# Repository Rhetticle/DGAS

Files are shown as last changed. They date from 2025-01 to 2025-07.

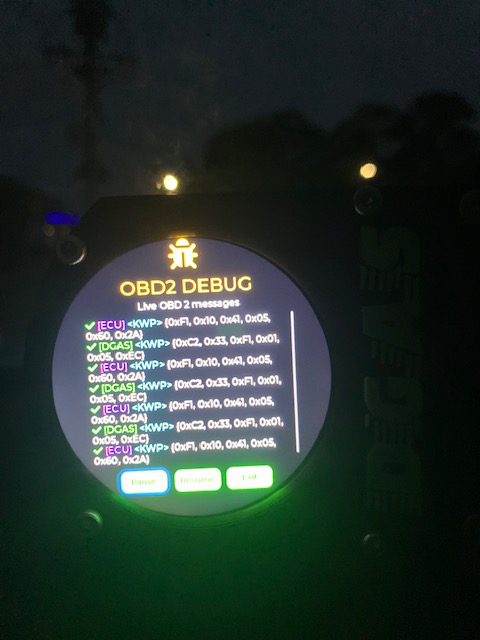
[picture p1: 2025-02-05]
Photos/obd2 debug.jpeg

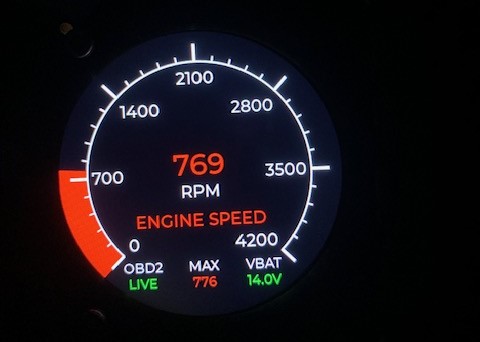
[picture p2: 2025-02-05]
Photos/engine spped small.jpeg

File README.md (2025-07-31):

# DGAS
Digital Gauge Awareness System to be used with any car with an OBD-2 port. 

dgas front


dgas

## Update
Version two of this device is currently in progress including a revised PCB and a major firmware upgrade ([DGOS](https://github.com/Rhetticle/DGOS)) 

## Overview
DGAS is a multi-function digital gauge that can measure any data available on a car's OBD-2 diagnostic port such as engine speed, vehicle speed, coolant temperature, manifold pressure etc. DGAS supports 3 out of the 4 OBD-2 buses namely ISO-9141, ISO-14320 (also known as KWP2000) and ISO-15765 (CAN, most common for newer cars) (SAE J-1850 is not supported). All data measured from the car's ECU is displayed on a 2.1 inch circular TFT-LCD display with a 16-bit color depth.  

DGAS is also capable of performing vehicle and engine diagnostics by reading and displaying current and pending diagnostic trouble codes (DTCs).

## UI

The DGAS UI allows the user to configure and interact with multiple features of the gauge such as measurement parameter as well as watch live OBD2 messages sent from DGAS to the ECU and the response from the ECU which is useful for debugging purposes.

### Main Gauge UI
The gauge UI display the current parameter being measured as well as OBD2 status, maximum parameter value reached so far and battery voltage. Each parameter is color coded.

  

  
  

  

### Menu



### Measure
The measure UI let's the user chose between 1 of 8 different parameters assuming the vehicle DGAS is connected to supports these parameters.



### OBD2 Debug
The OBD2 Debug shows the live data being sent from DGAS and received from the ECU. Each message consists of a header with a status (green tick for ok or red cross for error), a device (either DGAS or ECU) and the bus being used as well as the raw data itself, or an error message if an error occurred on the bus.





### DTC
This UI allows the driver to perform diagnostics on their engine by reading the current/pending diagnostic trouble codes (DTCs). DGAS will send the OBD2 DTC request message and list the codes found if any. For example, if we unplug the cable which connects above the air filter containing the MAF sensor and intake air temperature sensor DGAS reports the following:




As above two codes were found namely P0102 and P0133. We can use SAE-J2012 to find the meaning of each which correspond to MAF and intake air temperature errors as expected.
dtcMeaning

### Self-Test
This screen allows the user to get DGAS to run a test on its hardware. DGAS will test for read access to the entire DRAM memory array and entire flash array as well as test that the accelerometer is also functioning correctly. DGAS will report some statistics on each test such as the time taken to run each test, access speed and acceleration values for the accelerometer.




### Settings
The settings allow the user to configure the default parameter to measure on start-up as well as which OBD2 bus to us on start-up. The configuration is saved to external flash and read on each start-up.




### About
This screen explains what DGAS is and has a QR code which directs users to this GitHub repository



## Hardware Details
* Microcontroller - STM32F746ZGT7 (QFP-144)
* External DRAM - IS42S16100H-7TL (16-Mbit) (50-TSOP)
* External Flash - W25Q256JVEIQ (256-Mbit) (8-WSON)
* TFT-LCD Display - Generic 2.1 inch available [here](https://www.aliexpress.com/item/1005007721123612.html?spm=a2g0o.order_list.order_list_main.11.238a18026Mdnp0) (ST7701 driver IC)
* CAN Transceiver - SN65HVD232QDRQ1 (8-SOIC)
* ISO-9141 Transceiver - L9613B013TR (8-SOIC)
* Accelerometer - LIS3DHTR (16-LGA)

The STM32F746ZGT7 was chosen for it's large 1MB of internal flash (needed to store LVGL code) as well as it's LTDC and FMC peripherals needed to drive the TFT-LCD display and interface with external DRAM respectively. External DRAM was needed to store the frame buffers for the display. As the display was 480x480 with a 16-bit color depth, one frame buffer occupies 460800 bytes. Since DGAS uses double buffering and the TFT-LCD display being used has no internal memory, both buffers must be stored in the DRAM which takes up around half of the 2 MiB available. External flash is being used to store large GUI objects such as images and fonts.

DGAS connects to the car's OBD-2 port via the main DB-15 connector using a DB-15 to OBD-2 cable. The main power connection should be connected to any wire within the car which carries the ignition signal so that DGAS is only powered when the vehicle is on.

The casing for DGAS was designed in Fusion 360 and printed in black ABS as it was found that PLA cannot hold up to the temperatures reached within a car during summer and begins to soften when given enough exposure.

## Firmware Details
Checkout DGAS Firmware for more details on firmware and low-level drivers.
### LVGL
All UI elements for the display were done through the LVGL graphics library as well as the EEZ-Studio UI designer tool.

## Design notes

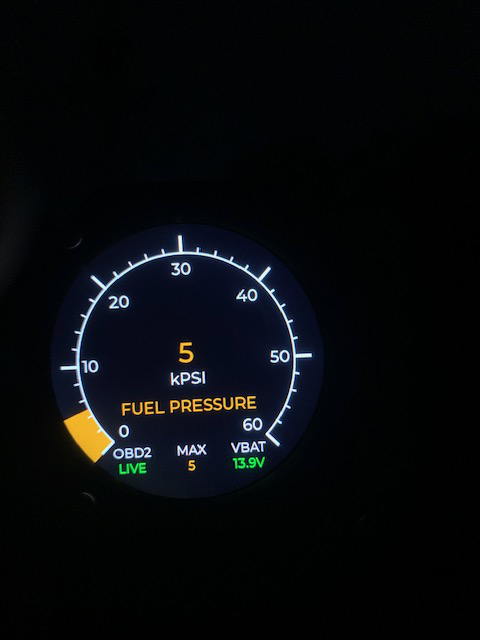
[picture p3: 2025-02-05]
Photos/fuel pressure.jpeg

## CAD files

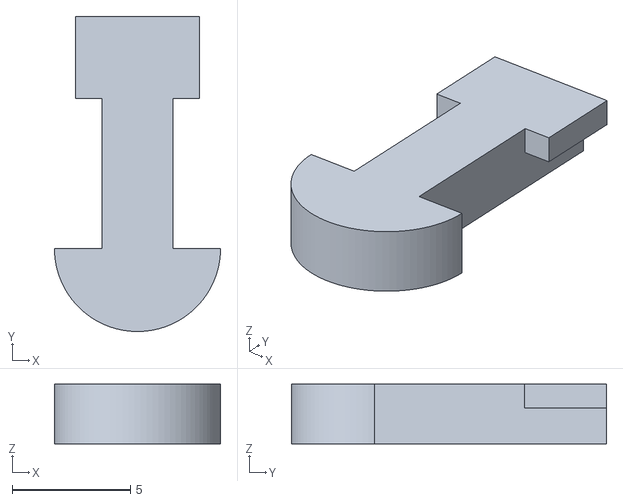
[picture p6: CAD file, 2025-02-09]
DGAS STL/Button Pin.stl
7.02 x 13.3 x 2.52

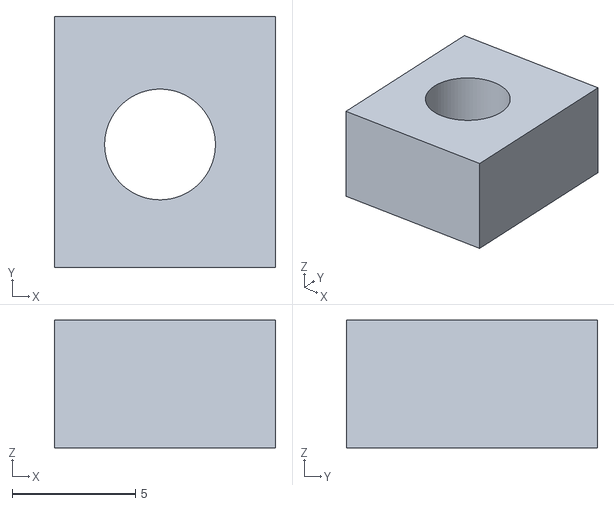
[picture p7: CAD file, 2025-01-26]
DGAS STL/Mount/Mounting tab.stl
9.00 x 10.2 x 5.20

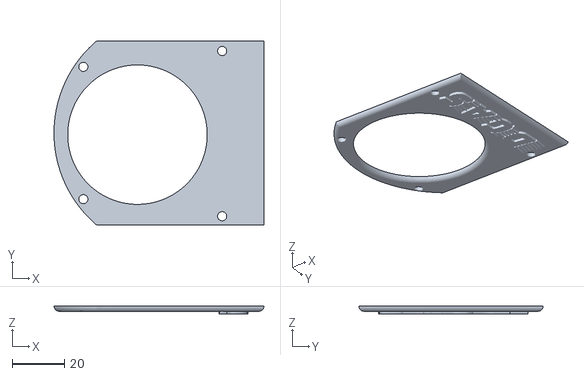
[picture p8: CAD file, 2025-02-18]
DGAS STL/Casing/DGAS Casing Top.stl
80.2 x 70.4 x 3.00

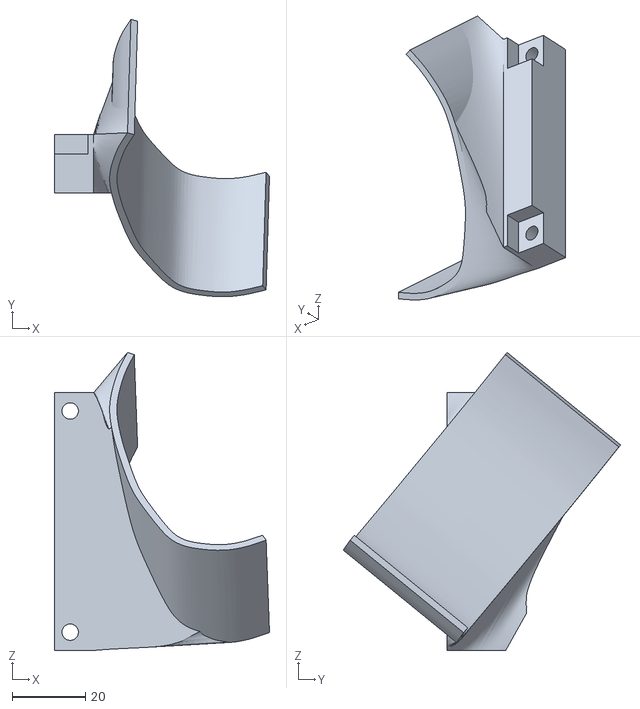
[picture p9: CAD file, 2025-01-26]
DGAS STL/Mount/A-Pillar mount.stl
58.8 x 75.8 x 81.4

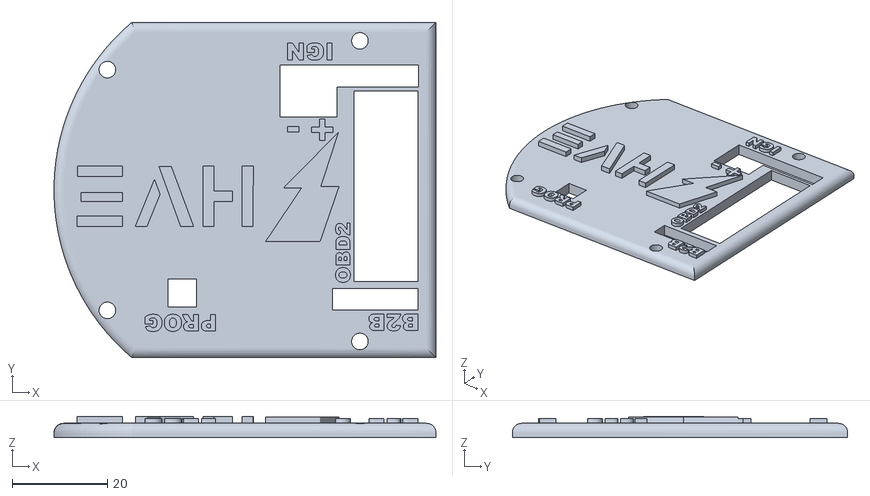
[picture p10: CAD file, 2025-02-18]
DGAS STL/Casing/DGAS Casing Bottom.stl
80.2 x 70.4 x 4.42

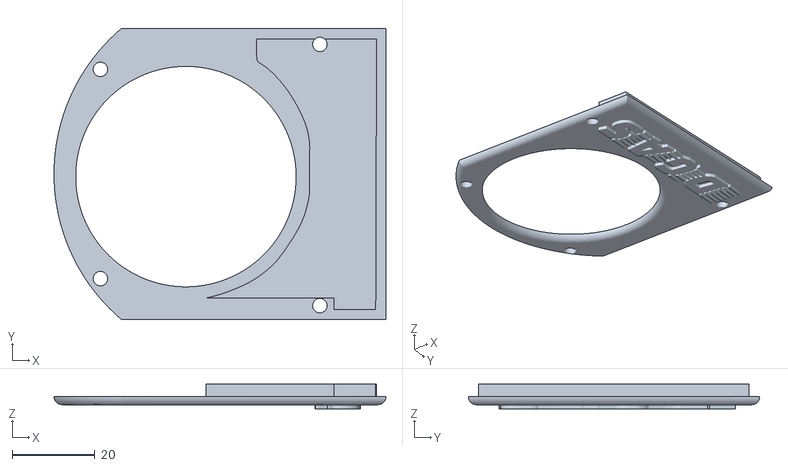
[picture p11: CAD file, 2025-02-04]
DGAS STL/Casing/DGAS Casing Top with branding.stl
80.2 x 70.4 x 6.00

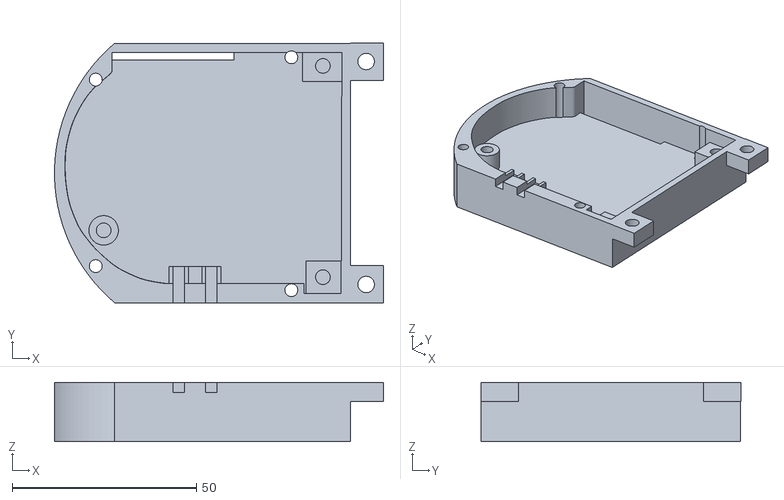
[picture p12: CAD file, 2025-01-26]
DGAS STL/Casing/DGAS Casing Middle.stl
89.2 x 70.4 x 16.0

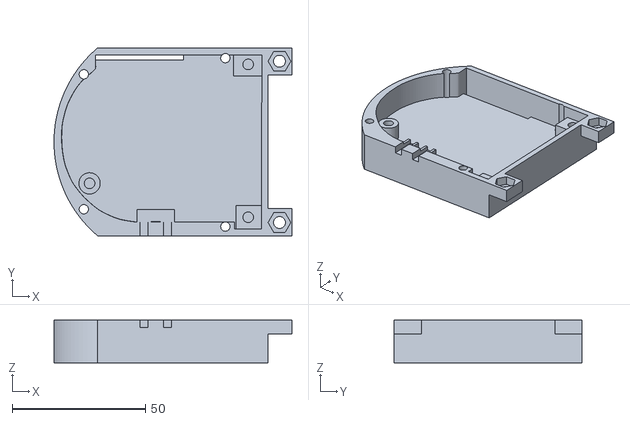
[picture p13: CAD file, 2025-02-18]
DGAS STL/Casing/DGAS Casing Middle Embedded Nut.stl
89.2 x 70.3 x 16.0

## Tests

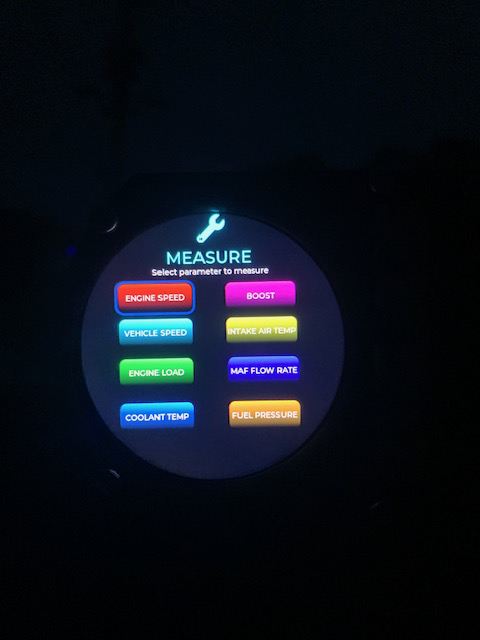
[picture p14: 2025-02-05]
Photos/measure.jpeg

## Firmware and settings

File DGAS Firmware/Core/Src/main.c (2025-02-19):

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
/* Includes ------------------------------------------------------------------*/
#include "main.h"

/* USER CODE BEGIN Includes */
#include "ST7701.h"
#include "LIS3DH.h"
#include <string.h>
#include <stdbool.h>
#include <stdlib.h>
#include <stdio.h>
#include "lvgl.h"
#include "ui.h"
#include "OBD2.h"
#include "ISO9141_KWP.h"
#include "OBD_Debug.h"
#include "quadspi.h"
#include "gauge.h"
#include "buttons.h"
/* USER CODE END Includes */

ADC_HandleTypeDef hadc1;

CAN_HandleTypeDef hcan1;
CAN_HandleTypeDef hcan2;

DMA2D_HandleTypeDef hdma2d;

I2C_HandleTypeDef hi2c4;

LTDC_HandleTypeDef hltdc;

QSPI_HandleTypeDef hqspi;

SPI_HandleTypeDef hspi1;

TIM_HandleTypeDef htim1;

UART_HandleTypeDef huart4;

SDRAM_HandleTypeDef hsdram1;

void SystemClock_Config(void);
static void MPU_Config(void);
static void MX_GPIO_Init(void);
static void MX_CAN1_Init(void);
static void MX_CAN2_Init(void);
static void MX_FMC_Init(void);
static void MX_I2C4_Init(void);
static void MX_QUADSPI_Init(void);
static void MX_SPI1_Init(void);
static void MX_UART4_Init(void);
static void MX_LTDC_Init(void);
static void MX_TIM1_Init(void);
static void MX_ADC1_Init(void);
static void MX_DMA2D_Init(void);
/* USER CODE BEGIN 0 */
#define SDRAM_START_ADDR 0xC0000000
#define LVGL_GRAM_ADDR 0xC007A120
#define SDRAM_SIZE 0x200000

uint8_t* ltdc = (uint8_t*) SDRAM_START_ADDR;

void fmc_init(void) {
	  FMC_SDRAM_CommandTypeDef Command;
	  /* Step 1 and Step 2 already done in HAL_SDRAM_Init() */
	  /* Step 3: Configure a clock configuration enable command */
	   Command.CommandMode            = FMC_SDRAM_CMD_CLK_ENABLE; /* Set MODE bits to "001" */
	   Command.CommandTarget          = FMC_SDRAM_CMD_TARGET_BANK1; /* configure the Target Bank bits */
	   Command.AutoRefreshNumber      = 1;
	   Command.ModeRegisterDefinition = 0;
	   HAL_SDRAM_SendCommand(&hsdram1, &Command, 0xfff);
	   HAL_Delay(1); /* Step 4: Insert 100 us minimum delay - Min HAL Delay is 1ms */
	   /* Step 5: Configure a PALL (precharge all) command */
	   Command.CommandMode            = FMC_SDRAM_CMD_PALL; /* Set MODE bits to "010" */
	   HAL_SDRAM_SendCommand(&hsdram1, &Command, 0xfff);
	   /* Step 6: Configure an Auto Refresh command */
	   Command.CommandMode            = FMC_SDRAM_CMD_AUTOREFRESH_MODE; /* Set MODE bits to "011" */
	   Command.AutoRefreshNumber      = 2;
	   HAL_SDRAM_SendCommand(&hsdram1, &Command, 0xfff);
	   /* Step 7: Program the external memory mode register */
	   Command.CommandMode            = FMC_SDRAM_CMD_LOAD_MODE;/*set the MODE bits to "100" */
	   Command.ModeRegisterDefinition =  (uint32_t)0 | 0<<3 | 2<<4 | 0<<7 | 1<<9;
	   HAL_SDRAM_SendCommand(&hsdram1, &Command, 0xfff);
	   /* Step 8: Set the refresh rate counter - refer to section SDRAM refresh timer register in RM0455 */
	   /* Set the device refresh rate
	    * COUNT = [(SDRAM self refresh time / number of row) x  SDRAM CLK] – 20
	            = [(64ms/4096) * 100MHz] - 20 = 1562.5 - 20 ~ 1542 */
	   HAL_SDRAM_ProgramRefreshRate(&hsdram1, 1105);
}

void fill_mem(uint16_t value) {
	for (int i = 0; i < 480*480*2; i++) {
			ltdc[i] = value;
	}
}

void my_flush_cb(lv_display_t* disp, const lv_area_t* area, uint8_t* map) {
	 if(lv_display_is_double_buffered(disp) && lv_display_flush_is_last(disp)) {
	            HAL_LTDC_SetAddress_NoReload(&hltdc, (uint32_t)map, 0);
	            HAL_LTDC_Reload(&hltdc, LTDC_RELOAD_VERTICAL_BLANKING);
	        }

	lv_display_flush_ready(disp);
}


void start_up_anim() {
	int16_t scale = 0;

	while(scale < 4200) {
		lv_arc_set_value(objects.gauge_arc, scale);
		lv_timer_handler();
		HAL_Delay(5);
		scale += 150;
	}
	while (scale >= 0) {
		lv_arc_set_value(objects.gauge_arc, scale);
		lv_timer_handler();
		HAL_Delay(5);
		scale -= 150;
	}
}

void dgas_init(lv_display_t* display) {
	accel_init();
	start_up_anim();
	lv_label_set_text(objects.obd_status_label, "#00FFFF INIT#");
	lv_refr_now(display);
}

lv_display_t* display_init(void) {
	lcd_init();
	fmc_init();
	lv_init();
	lv_tick_set_cb(HAL_GetTick);
	lv_display_t* display = lv_display_create(480, 480);
	lv_display_set_buffers(display, (void*) SDRAM_START_ADDR + SDRAM_SIZE - 480*480*2*2, (void*) SDRAM_START_ADDR, 480*480*2, LV_DISP_RENDER_MODE_DIRECT);
	lv_display_set_flush_cb(display, my_flush_cb);
	CSP_QUADSPI_Init();
	CSP_QSPI_EnableMemoryMappedMode();
	ui_init();
	return display;
}

lv_display_t* display;
/* USER CODE END 0 */

/**
  * @brief  The application entry point.
  * @retval int
  */
int main(void)
{
  /* MPU Configuration--------------------------------------------------------*/
  MPU_Config();

  /* Enable I-Cache---------------------------------------------------------*/
  SCB_EnableICache();

  /* Enable D-Cache---------------------------------------------------------*/
  SCB_EnableDCache();

  /* MCU Configuration--------------------------------------------------------*/

  /* Reset of all peripherals, Initializes the Flash interface and the Systick. */
  HAL_Init();

  /* Configure the system clock */
  SystemClock_Config();

  /* Initialize all configured peripherals */
  MX_GPIO_Init();
  MX_CAN1_Init();
  MX_CAN2_Init();
  MX_FMC_Init();
  MX_I2C4_Init();
  MX_QUADSPI_Init();
  MX_SPI1_Init();
  MX_LTDC_Init();
  MX_TIM1_Init();
  MX_ADC1_Init();
  MX_DMA2D_Init();
  /* USER CODE BEGIN 2 */
  // We will immediately pull L and K lines high
  HAL_GPIO_WritePin(GPIOC, ISO9141_K, 1);
  HAL_GPIO_WritePin(GPIOA, ISO9141_L, 0);
  display = display_init();
  dgas_init(display);

  uint32_t tick = 0;
  OBDBus kwp;
  GaugeState state;
  gauge_init(&state, &kwp);
  debug_init(kwp.id);
  lv_label_set_text(objects.obd_status_label, "#00FF00 LIVE#");
  lv_refr_now(display);
  uint16_t measure = 0;
  HAL_ADC_Start_IT(&hadc1);

  lv_indev_t* indev = lv_indev_create();
  init_buttons(indev);
  init_events(&state);
  /* USER CODE END 2 */

  /* Infinite loop */
  /* USER CODE BEGIN WHILE */
  while (1)
  {
	 if ((HAL_GetTick() > tick) && ((lv_screen_active() == objects.gauge_main_ui) || (lv_screen_active() == objects.obd2_debug))) {
		 state.param->measure(state.bus, &measure);
		 if (lv_screen_active() == objects.obd2_debug) {
			 debug_flush();
		 } else {
			 gauge_update(&state, measure);
		 }
		 tick = HAL_GetTick();
	 } else if ((HAL_GetTick() > tick + 500) && (lv_screen_active() != objects.gauge_main_ui)) {
		 obd2_dummy_request(&kwp);
		 tick = HAL_GetTick();
	 }
	 lv_timer_handler();
    /* USER CODE END WHILE */

    /* USER CODE BEGIN 3 */
  }
  /* USER CODE END 3 */
}

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
/* MPU Configuration */

void MPU_Config(void)
{
  MPU_Region_InitTypeDef MPU_InitStruct = {0};

  /* Disables the MPU */
  HAL_MPU_Disable();

  /** Initializes and configures the Region and the memory to be protected
  */
  MPU_InitStruct.Enable = MPU_REGION_ENABLE;
  MPU_InitStruct.Number = MPU_REGION_NUMBER0;
  MPU_InitStruct.BaseAddress = 0x90000000;
  MPU_InitStruct.Size = MPU_REGION_SIZE_32MB;
  MPU_InitStruct.SubRegionDisable = 0;
  MPU_InitStruct.TypeExtField = MPU_TEX_LEVEL0;
  MPU_InitStruct.AccessPermission = MPU_REGION_FULL_ACCESS;
  MPU_InitStruct.DisableExec = MPU_INSTRUCTION_ACCESS_DISABLE;
  MPU_InitStruct.IsShareable = MPU_ACCESS_NOT_SHAREABLE;
  MPU_InitStruct.IsCacheable = MPU_ACCESS_CACHEABLE;
  MPU_InitStruct.IsBufferable = MPU_ACCESS_BUFFERABLE;

  HAL_MPU_ConfigRegion(&MPU_InitStruct);
  /* Enables the MPU */
  HAL_MPU_Enable(MPU_PRIVILEGED_DEFAULT);

}

/**
  * @brief  This function is executed in case of error occurrence.
  * @retval None
  */
void Error_Handler(void)
{
  /* USER CODE BEGIN Error_Handler_Debug */
  /* User can add his own implementation to report the HAL error return state */
  __disable_irq();
  while (1)
  {
  }
  /* USER CODE END Error_Handler_Debug */
}

#ifdef  USE_FULL_ASSERT
/**
  * @brief  Reports the name of the source file and the source line number
  *         where the assert_param error has occurred.
  * @param  file: pointer to the source file name
  * @param  line: assert_param error line source number
  * @retval None
  */
void assert_failed(uint8_t *file, uint32_t line)
{
  /* USER CODE BEGIN 6 */
  /* User can add his own implementation to report the file name and line number,
     ex: printf("Wrong parameters value: file %s on line %d\r\n", file, line) */
  /* USER CODE END 6 */
}
#endif /* USE_FULL_ASSERT */

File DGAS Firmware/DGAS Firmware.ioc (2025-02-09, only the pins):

Mcu.UserName=STM32F746ZGTx
PA1.Signal=LTDC_R2
PA10.Signal=GPIO_Output
PA11.Signal=CAN1_RX
PA12.Signal=CAN1_TX
PA13.Signal=SYS_JTMS-SWDIO
PA14.Signal=SYS_JTCK-SWCLK
PA2.GPIO_Label=VBAT [ADC]
PA2.Signal=ADCx_IN2
PA3.Signal=LTDC_B5
PA4.Signal=LTDC_VSYNC
PA5.Signal=LTDC_R4
PA6.Signal=LTDC_G2
PA7.Signal=FMC_SDNWE
PB0.Signal=LTDC_R3
PB1.Signal=LTDC_R6
PB10.Signal=LTDC_G4
PB11.Signal=LTDC_G5
PB12.Signal=CAN2_RX
PB13.Signal=CAN2_TX
PB14.GPIO_Label=BTN_NAV [INT]
PB14.Signal=GPXTI14
PB15.GPIO_Label=BTN_SEL [INT]
PB15.Signal=GPIO_Input
PB2.Signal=QUADSPI_CLK
PB3.Signal=SPI1_SCK
PB4.GPIO_Label=LCD_CS
PB4.Signal=GPIO_Output
PB5.Signal=SPI1_MOSI
PB6.Signal=QUADSPI_BK1_NCS
PB7.GPIO_Label=LCD_NRST
PB7.Signal=GPIO_Output
PB8.Signal=LTDC_B6
PB9.Signal=LTDC_B7
PC0.Signal=LTDC_R5
PC10.Signal=UART4_TX
PC11.Signal=UART4_RX
PC2.Signal=FMC_SDNE0
PC3.Signal=FMC_SDCKE0
PC6.Signal=LTDC_HSYNC
PC7.Signal=LTDC_G6
PD0.Signal=FMC_D2_DA2
PD1.Signal=FMC_D3_DA3
PD10.Signal=FMC_D15_DA15
PD11.GPIO_Label=HOST_SENSE [IN]
PD11.Signal=GPIO_Input
PD12.Signal=I2C4_SCL
PD13.Signal=I2C4_SDA
PD14.Signal=FMC_D0_DA0
PD15.Signal=FMC_D1_DA1
PD3.Signal=LTDC_G7
PD6.Signal=LTDC_B2
PD8.Signal=FMC_D13_DA13
PD9.Signal=FMC_D14_DA14
PE0.Signal=FMC_NBL0
PE1.Signal=FMC_NBL1
PE10.Signal=FMC_D7_DA7
PE11.Signal=FMC_D8_DA8
PE12.Signal=FMC_D9_DA9
PE13.Signal=FMC_D10_DA10
PE14.Signal=FMC_D11_DA11
PE15.Signal=FMC_D12_DA12
PE2.Signal=QUADSPI_BK1_IO2
PE7.Signal=FMC_D4_DA4
PE8.Signal=FMC_D5_DA5
PE9.Signal=FMC_D6_DA6
PF0.Signal=FMC_A0
PF1.Signal=FMC_A1
PF10.Signal=LTDC_DE
PF11.Signal=FMC_SDNRAS
PF12.Signal=FMC_A6
PF13.Signal=FMC_A7
PF14.Signal=FMC_A8
PF15.Signal=FMC_A9
PF2.Signal=FMC_A2
PF3.Signal=FMC_A3
PF4.Signal=FMC_A4
PF5.Signal=FMC_A5
PF6.Signal=QUADSPI_BK1_IO3
PF8.Signal=QUADSPI_BK1_IO0
PF9.Signal=QUADSPI_BK1_IO1
PG0.Signal=FMC_A10
PG10.Signal=LTDC_G3
PG11.Signal=LTDC_B3
PG12.Signal=LTDC_B4
PG15.Signal=FMC_SDNCAS
PG4.Signal=FMC_A14_BA0
PG6.Signal=LTDC_R7
PG7.Signal=LTDC_CLK
PG8.Signal=FMC_SDCLK
PH0/OSC_IN.Signal=RCC_OSC_IN
PH1/OSC_OUT.Signal=RCC_OSC_OUT

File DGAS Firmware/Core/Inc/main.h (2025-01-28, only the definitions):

#define VBAT_Pin GPIO_PIN_2
#define VBAT_GPIO_Port GPIOA
#define BTN_NAV_Pin GPIO_PIN_14
#define BTN_NAV_GPIO_Port GPIOB
#define BTN_NAV_EXTI_IRQn EXTI15_10_IRQn
#define BTN_SEL_Pin GPIO_PIN_15
#define BTN_SEL_GPIO_Port GPIOB
#define HOST_SENSE_Pin GPIO_PIN_11
#define HOST_SENSE_GPIO_Port GPIOD
#define LCD_CS_Pin GPIO_PIN_4
#define LCD_CS_GPIO_Port GPIOB
#define LCD_NRST_Pin GPIO_PIN_7
#define LCD_NRST_GPIO_Port GPIOB

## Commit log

2024-12-29 Add polygons to inner power layer
    [Accelerometer.SchDoc]
2024-12-29 Finish routing connectors for power and board to board connections
    [DGAS.PrjPcb, Digital - STM32.SchDoc, Misc.SchDoc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]
2024-12-30 Finalised routing and polygon pours, rectify DRC errors
    [DGAS.PrjPcb, DRAM and QSPI.SchDoc, Digital - STM32.SchDoc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]
2024-12-30 Change CAN transceiver from MCP2551 to SN65HVD232QDRQ1 to allow for 3V3 supply for CAN
    [OBD2.SchDoc]
2024-12-30 Change right angle DB15 connector to vertical
    [Misc.SchDoc, OBD2.SchDoc]
2024-12-30 Remove solder mask over speaker connections
    [DRAM and QSPI.SchDoc, Digital - STM32.SchDoc, LCD.SchDoc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]
2024-12-30 Modify mounting holes and add logos
2024-12-30 Add pull up resistor to LCD chip select. Add debouncing capacitors to navigation and select buttons
    [LCD.SchDoc, Misc.SchDoc, OBD2.SchDoc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]
2024-12-30 Add basic driver for accelerometer
    [PCB1.DRL, PCB1_Board.gbr, PCB1_Bottom_3D_Body.gbr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]
2024-12-31 Fix reversed pins on LCD FPC connector
    [LCD.SchDoc]
2024-12-31 Start driver for flash memory, add more accurate 3d model of DB15 connector on PCB
    [LCD.SchDoc, OBD2.SchDoc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]
2025-01-01 Add 3d body to FPC connector on PCB to assist with enclosure modelling
    [LCD.SchDoc]
2025-01-01 Add STL directory and STL files of prototype casing
    [DGAS Casing Bottom.stl, DGAS Casing Middle.stl, DGAS Casing Top.stl]
2025-01-01 Increase clearance on casing top piece
    [DGAS Casing Top.stl]
2025-01-05 Start driver for ST7701 display driver IC. Modify casing top and middle to better house LCD display
    [DGAS Casing Middle.stl, DGAS Casing Top.stl]
2025-01-06 Modify firmware to use STM32F746ZGT7 instead of STM32F750Z8T6
    [DGAS Casing Middle.stl]
2025-01-08 Add code to verify that FMC can access DRAM. Add code to verify that LCD display is working correctly.
    [DGAS Firmware.ioc]
2025-01-08 Add driver for QSPI flash. Basic read and write enable functionality working
2025-01-10 Fix bug in LVGL flush callback by swapping for loop order
    [LIS3DH.c, main.c]
2025-01-11 Fix random accelerometer measurements bug
    [LIS3DH.c]
2025-01-14 Modify PCB. Simplify circuitry to sense being the host device. Add circuitry to control the L-Line for KWP2000 initialisation
    [Digital - STM32.SchDoc, OBD2.SchDoc]
2025-01-14 Add working OBD2 driver for KWP2000 protocol. Verified with testing
    [PCB1.DRL, PCB1_Board.gbr, PCB1_Bottom_3D_Body.gbr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]
2025-01-26 Add complete gauge UI with all screens, add -O2 optimisation flag to gcc to improve LVGL performance
    [A-Pillar mount.stl, Button Pin.stl, DGAS Casing Middle.stl]
2025-01-26 Integrate GaugeState and GaugeParam structs into main super loop
    [Mounting tab.stl]
2025-01-27 Add ADC functionality to measure battery voltage
2025-01-28 Add buttons.c and buttons.h. Add basic navigation and selection functionality of buttons working
2025-01-28 Fix incorrect PIDs in OBD2.c functions
    [OBD2.c, buttons.c, gauge.c]
2025-01-29 Fix gauge_load_param to reset that gauge's max value to zero
    [DGAS Firmware.ioc, buttons.c, gauge.c]
2025-01-29 Modify button coloring in menu UI. Simplify while loop in main by moving logic into enc_read() in buttons.c
2025-01-30 Fix no button focus on first screen swtich
    [OBD2.c, buttons.c, gauge.c]
2025-01-30 Modify menu_event_cb() to work with other menu buttons
2025-01-31 Modify button pins to have semicular top. Modify casing middle to fit embedded M4 nut
    [Button Pin.stl, DGAS Casing Middle Embedded Nut.stl]
2025-02-04 Add speaker.h and speaker.c to firmware. Modify casing 3D models
    [DGAS Casing Bottom.stl, DGAS Casing Top with branding.stl]
2025-02-05 Add photos. Add iso15765.h and iso15765.c to firmware for CAN bus support for OBD2
2025-02-07 iso15765 driver ready for testing. Configure CAN filter to only accept messages from ID range of ECU
2025-02-08 Fix bug with uint8_t being unrecognised by removing lvgl/demos directory
    [ISO9141_KWP.c, ISO9141_KWP.h, OBD2.c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]
2025-02-09 Add new UI to include DTC and self-test screens. Modify lv_dropdown.c to wrap around when at bottom of dropdown list.
    [Button Pin.stl]
2025-02-09 Fix auto-focus bug in settings screen by adjusting event handlers to response to LV_EVENT_CLICKED not LV_EVENT_PRESSED
    [DGAS Firmware.ioc, main.c]
2025-02-10 Add more functionality to selftest.c. Can now test DRAM, Flash and accelerometer
2025-02-10 Fix return value in read_gauge_config from HAL_ERROR to HAL_OK
    [OBD2.c, gauge.c, main.c]
2025-02-10 Add modified UI to firmware. Modify self-test code to show device statistics on successfull device test.
2025-02-18 Modify ISO9141/KWP driver to support DTC functionality.
    [DGAS Casing Bottom.stl, DGAS Casing Middle Embedded Nut.stl, DGAS Casing Top.stl]
2025-02-20 Neaten kwp_get_dtcs() function in ISO9141/KWP driver

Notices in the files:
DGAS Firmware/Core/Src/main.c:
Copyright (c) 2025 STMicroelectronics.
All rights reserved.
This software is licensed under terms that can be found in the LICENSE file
